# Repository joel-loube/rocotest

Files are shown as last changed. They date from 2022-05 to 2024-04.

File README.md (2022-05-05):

# rocotest
Rotary Compression Tester

This repository contains code, models, and instructions for a DIY compression tester for rotary engines.

**Why is a special compression tester needed for a rotary engine?**

Because each rotor has 3 faces, any one of which can have differing compression numbers from the other two, and there is only one hole to measure compression from. This means that we need a compression tester that is able to figure out which face each compression pulse is coming from and separate them.

**Why cant I use a regular compression tester?**

You certainly can, but it doenst show you the whole picture. If the compression on one face of a rotor is bad, that will not show up on a regular tester, because the pulses from the other two faces are higher.

**What components do I need for this?**

1. A set of 3d printed parts for the case.
2. a screen: https://www.amazon.ca/gp/product/B07YNP2L95
3. an arduino nano: https://www.amazon.ca/gp/product/B071NMD14Y
4. a 200 psi pressure transducer: https://www.amazon.ca/gp/product/B0748CVN3F
5. a 1/4 to 1/8 npt adapter https://www.amazon.ca/gp/product/B0044F8YXW
6. a 14mm long-rech spark plug non-fouler https://www.amazon.ca/gp/product/B000BYGJQY
7. some hookup wire (get the small stuff, nothing here needs high amperage, and its easier to fit into small spaces)
8. at least 9 heat set inserts, M2 X D4.0 X L3.0: https://www.aliexpress.com/item/4000232858343.html
9. at least 9 screws, m2 x 5mm long: https://www.aliexpress.com/item/4000282581926.html
10. a soldering iron
11. a usb cable
12. jbweld

**How do I assemble this?**

1. Print the parts
2. heat set all of the inserts into the parts (2 in the top of the case, and 7 in the bottom)
3. drop the arduino into the slot, and use the small tab to fix it down
4. insert your selected sensor cable into the hole, fix it down with the clamp (if the clamp is too loose, use layers of heatshrink to enlarge it until there is a snug fit.
5. solder the wires from the sensor to the board, power to the 5v pin, ground to the GND pin, and signal to the A0 pin
6. remove any headers from the screen, you will not be able to fit them in
7. solder wires from the back of the screen to the arduino, power to the 5v pin (2 wires there, annoying but doable), ground to the other GND pin, SCL to A5, SDA to A4.
8. use the strap and 2 screws to fix the screen to the front panel. These screens are fragile so be careful. You should not need to trim anything, but it is possible.
9. plug your usb cable in and into a computer
10. load up arduino and load the sketch
11. make sure you have the Adafruit_SSD1306 library and the Adafruit_GFX library in your installed arduino libraries
12. load the firmware onto the board
13. jbweld the npt adapter into the spark plug non fouler
14. teflon tape the sensor into the npt adapter
15. put some big heatshrink or tape around the whole thing if you want some extra grip or damage resistance
16. probably a good idea to put a rubber oring onto the non fouler, makes a better seal

**How do I use this?**

1. disconnect the sensor from the harness
2. screw it into a spark plu hole
3. plug it back in
4. plug the tester into a usb power bank, or a pc
5. wait until it says you can crank the engine
6. do so

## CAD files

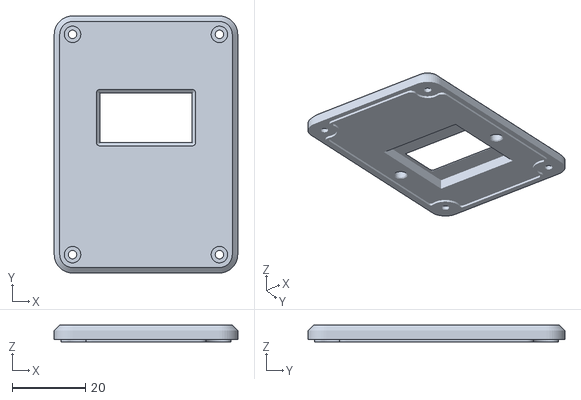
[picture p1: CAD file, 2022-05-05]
Models/Top.stl
50.0 x 70.0 x 4.60

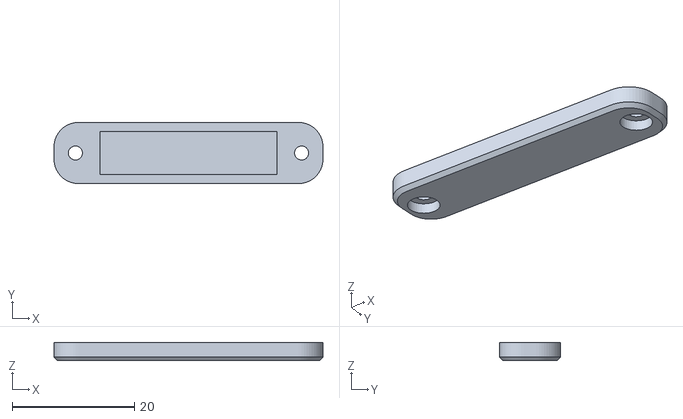
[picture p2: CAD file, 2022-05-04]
Models/Screen Clamp.stl
44.0 x 10.0 x 3.00

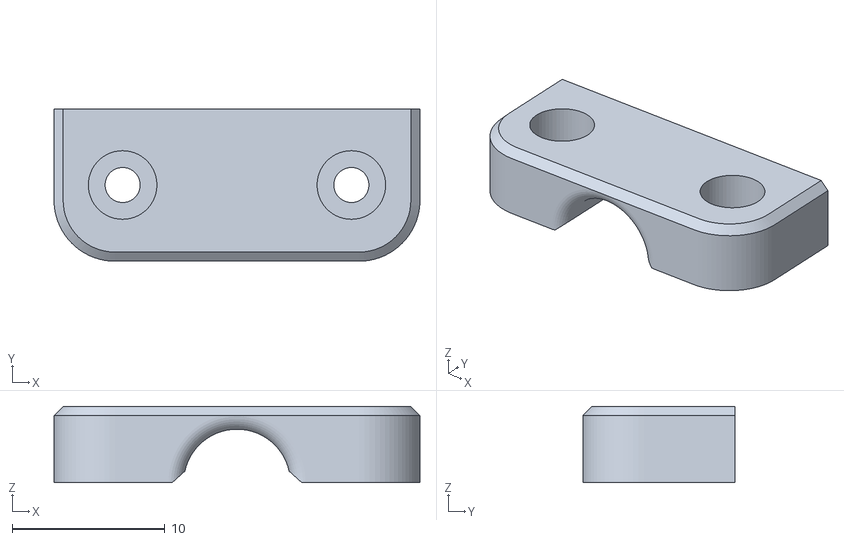
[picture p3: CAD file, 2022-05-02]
Models/Cable Clamp.stl
24.0 x 10.0 x 5.00

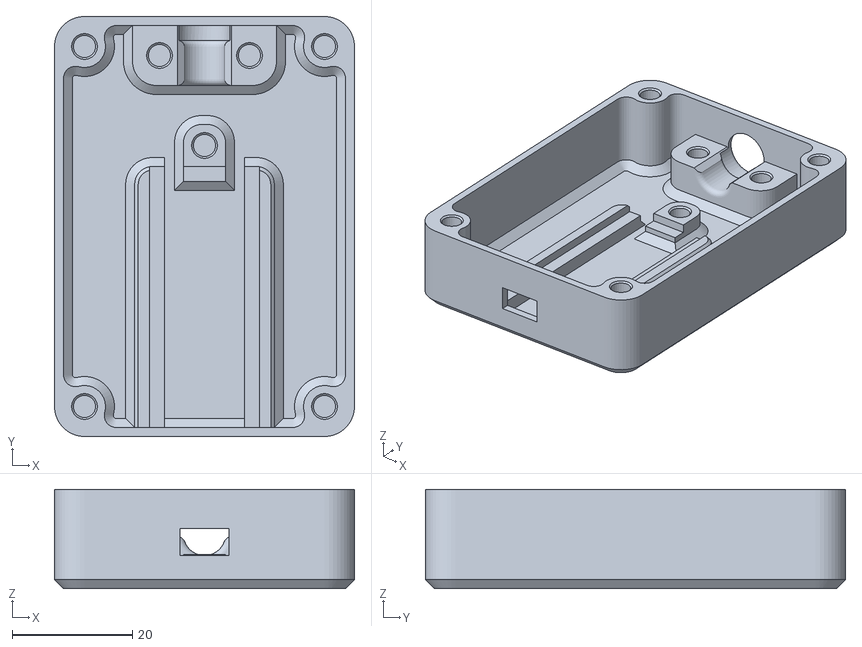
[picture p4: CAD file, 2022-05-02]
Models/Bottom.stl
50.0 x 70.0 x 16.5

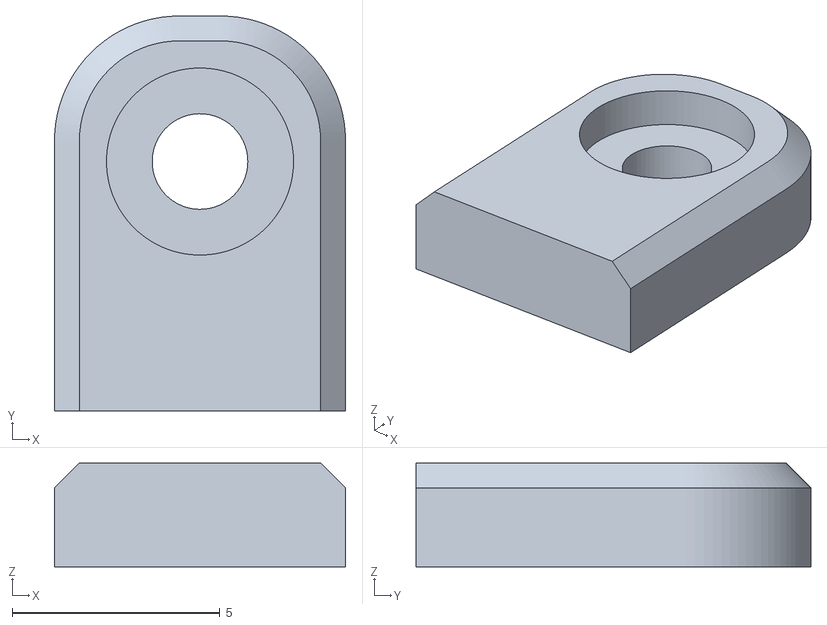
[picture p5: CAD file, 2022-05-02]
Models/Board Clamp.stl
7.00 x 9.50 x 2.50

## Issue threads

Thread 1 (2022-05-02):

normalize results to 250 rpm

joel-loube, 2022-05-02:
is this a straight linear relationship?

reference: http://foxed.ca/index.php?page=rotarycalc

patrickmcquay, 2022-05-02:
are there formulas for this? Do we need to do this since we are outputting the RPM already?

patrickmcquay, 2022-05-02:
looks like the formula for this is:

corrected pressure = raw pressure * (8.6 + (-0.048 * rpm) + (0.000054 * sq(rpm)));

patrickmcquay, 2022-05-05:
correction, the formula is raw pressure +, not *.

patrickmcquay, 2022-05-05:
fixed by a45de1e5c4f3fc28132073f8f12287c4578f656b

Closed 2022-05-05.

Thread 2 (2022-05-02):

compensate for atmosphereic pressure

joel-loube, 2022-05-02:
take an initial reading before the compression pulses, adjust results accordingly

patrickmcquay, 2022-05-02:
looks like the way to do this is just take some measurements when the device boots and then subtract those from the raw measurements. Seems simple enough.

patrickmcquay, 2022-05-05:
fixed by 12d4db0345315b4d8e8bfd12903d2561f320a1b6

Closed 2022-05-05.

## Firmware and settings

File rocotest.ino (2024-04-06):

#include <SPI.h>
#include <Wire.h>
#include <Adafruit_GFX.h>
#include <Adafruit_SSD1306.h>

#define SCREEN_WIDTH 128 // OLED display width, in pixels
#define SCREEN_HEIGHT 64 // OLED display height, in pixels

#define DEAD_SPACE_CORRECTION_FACTOR 1.04f
#define SCALE_250_RPM_A0 8.6f              // polynom Fit a0 to norm values to 250rpm
#define SCALE_250_RPM_A1 -0.048f         // polynom Fit a1 to norm values to 250rpm
#define SCALE_250_RPM_A2 0.000054f       // polynom Fit a2 to norm values to 250rpm

#define SENSOR_PIN 0

// Declaration for an SSD1306 display connected to I2C (SDA, SCL pins)
Adafruit_SSD1306 display(SCREEN_WIDTH, SCREEN_HEIGHT, &Wire, -1);

/*Rotary Compression Tester
This code assumes you're using a 0-200 psi - 0.5-4.5 vdc pressure transducer connected to the AI0 pin.
You can use sensors with other pressure or voltage ranges but you'll need to modify the code.

Originally distributed by John Doss 2017.
refactored by Patrick McQuay, in 2020.
heavily modified using correction factors from code by Miro Bogner, in 2022.
*/

struct compressionRecord
{
    float facePressures[3];
    int rpm;
};

typedef struct compressionRecord CompressionRecord;

float ambientPressure = 0.0f;

void setup() {
  Serial.begin(9600);

  // SSD1306_SWITCHCAPVCC = generate display voltage from 3.3V internally
  if(!display.begin(SSD1306_SWITCHCAPVCC, 0x3C)) {
    Serial.println(F("SSD1306 allocation failed"));
    for(;;); // Don't proceed, loop forever
  }

  // Clear the buffer
  display.clearDisplay();
  display.display();

  Serial.begin(19200);      //serial speed
  delay(500);               //hang out for half a second
  
  for(int i = 0; i < 10; i++) {
    ambientPressure += mapRawToAbsolutePressure(analogRead(SENSOR_PIN));
    delay(10);
  }
  ambientPressure /= 10;

  displayIntro();
}

void loop() {
  CompressionRecord rec = performTest(); 
  displayResults(rec); 
}

float mapRawToAbsolutePressure(int rawValue) {
  return mapfloat((float)(rawValue), (1024.0f * 0.5f / 5.0f), (1024.0f * 4.5f / 5.0f), 0.0f, 200.0f);
}

float scaleTo250Rpm(float pressure, int rpm) {
  return pressure + (SCALE_250_RPM_A0 + (SCALE_250_RPM_A1 * rpm) + (SCALE_250_RPM_A2 * sq(rpm)));
}

int scaleSensorRead(int rawValue) {
  return (mapRawToAbsolutePressure(rawValue) - ambientPressure) * DEAD_SPACE_CORRECTION_FACTOR;
}

float mapfloat(float x, float in_min, float in_max, float out_min, float out_max)
{
  return (x - in_min) * (out_max - out_min) / (in_max - in_min) + out_min;
}

void displayIntro(void) {
  display.clearDisplay();

  display.invertDisplay(true);

  display.setTextSize(2);             
  display.setTextColor(SSD1306_WHITE);
  display.setCursor(0,0);
  display.println(" Welcome!");

  display.println("  ROTARY");
  display.println("  COMP.");
  display.println("  TESTER");
  
  display.display();

  delay(2000);
  
  display.invertDisplay(false);
  display.clearDisplay();
  
  display.setCursor(0,0);
  display.println(" Waiting.");
  display.println("  CRANK");
  display.println("  ENGINE");
  display.println("  NOW");

  display.display();
}

void displayResults(CompressionRecord rec) {
  display.clearDisplay();

  display.setTextSize(2);             // Draw 2X-scale text
  display.setTextColor(SSD1306_WHITE);        // Draw white text
  display.setCursor(0,0);             // Start at top-left corner
  display.print(F("RPM: "));
  display.println(min(9999, rec.rpm)); //Write RPM

  display.setTextSize(2);             // Draw 2X-scale text
  display.setTextColor(SSD1306_WHITE);
  
  display.print(F("F1: "));
  display.println(min(200, max(0, rec.facePressures[0])), 1);

  display.print(F("F2: "));
  display.println(min(200, max(0, rec.facePressures[1])), 1);

  display.print(F("F3: "));  
  display.println(min(200, max(0, rec.facePressures[2])), 1);
  
  display.display();
}

CompressionRecord performTest(void) {
  CompressionRecord rec;
  
  unsigned long oldTime = millis();           //record cycle begining time for RPM calculation
  
  for (int i = 0; i < 3; i++)         //the following code reads the sensor (in psi), looks for a peak pulse, assigns that to one of the faces, repeats the process for the next 2 faces and then moves on to the rest of the code
  {
    rec.facePressures[i] = 0;
    
    float currentPressure = scaleSensorRead(analogRead(SENSOR_PIN));
    
    while ((rec.facePressures[i] - currentPressure) <= 5) // this tests whether the current value has decayed by more than 5, if so, we are beyond the peak of the curve
    {
      if(currentPressure > rec.facePressures[i]) {
        rec.facePressures[i] = currentPressure;
      }
      
      currentPressure = scaleSensorRead(analogRead(SENSOR_PIN));
    }   
    
    float minimum = currentPressure;
    
    while((currentPressure - minimum) < 5) //similarly to above tests if we have risen by more than 5, if so we are beyond the trough of the curve
    {
      currentPressure = scaleSensorRead(analogRead(SENSOR_PIN));
      
      if (currentPressure < minimum) {
        minimum = currentPressure;
      }
    }
  }
  
  rec.rpm = (180000 / (millis() - oldTime));

  for (int i = 0; i < 3; i++) {
    rec.facePressures[i] = scaleTo250Rpm(rec.facePressures[i], rec.rpm);
  }
  
  return rec;
}

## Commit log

2022-05-02 remove unneeded libraries folder, use arduino library manager instead
2022-05-02 remove unneeded define for reset line that doesnt exist
    [rocotest.ino]
2022-05-02 remove unneeded first serial print in loop and extra var
2022-05-02 add models for 3d printing
    [Board Clamp.stl, Bottom.stl, Cable Clamp.stl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]
2022-05-02 Update README.md
    added assembly instructions.
2022-05-04 updated screen mounting to be closer to surface and less likely to break glass. Also fits more models of screen
    [Screen Clamp.stl, Top.stl]
2022-05-04 added ambient pressure compensation, also scaled the sensor from 0.5v to 4.5v instead of 0v to 5v
2022-05-05 add dead space correction factor
    [rocotest.ino]
2022-05-05 add 250rpm compensation, as well as much cleanup and interface niceness
2022-05-05 minor change to screen opening to be nicer to different screens, remove unneeded comment
    [Top.stl]
2024-04-06 Ensure the ambientPressure variable is initialized
    Previously, the variable 'ambientPressure' was not initialized, which
    potentially could lead to unpredictable behavior or incorrect results
    based on the random initial value. This commit initializes
    'ambientPressure' to zero ensuring a consistent starting state and
    preventing any such issues.
    [rocotest.ino]
2026-11-12 Fix RPM overflow and timing, add sample averaging, tidy serial/pin/display handling
2026-11-12 Use 1024 ADC steps for pressure scaling
